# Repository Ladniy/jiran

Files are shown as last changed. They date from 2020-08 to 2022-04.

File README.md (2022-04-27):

# Jiran

This work is licensed under a
[Creative Commons Attribution-NonCommercial-ShareAlike 4.0 International License][cc-by-nc-sa].

[][cc-by-nc-sa]

[cc-by-nc-sa]: http://creativecommons.org/licenses/by-nc-sa/4.0/
[cc-by-nc-sa-image]: https://licensebuttons.net/l/by-nc-sa/4.0/88x31.png
[cc-by-nc-sa-shield]: https://img.shields.io/badge/License-CC%20BY--NC--SA%204.0-lightgrey.svg

Jiran is a 6x4 matrix ergo keyboard with additional 3 thumb and 1 pinky keys.



Based on the [Jian](https://github.com/KGOH/Jian-Info) keyboard.

* __Author:__ [t.me/ladniys](https://t.me/ladniys) [u/Ladniy](https://reddit.com/u/Ladniy)
* __Layout:__ [keyboard-layout-editor.com](http://www.keyboard-layout-editor.com/#/gists/0547cd126f61f8c3f76b0a9952901da4)
* __Hardware Availability:__ [Free to use](https://github.com/Ladniy/jiran/releases/tag/v1.0)
* __Firmware:__ [QMK](https://github.com/qmk/qmk_firmware)
* __Building guide:__ [Wiki](https://github.com/Ladniy/jiran/wiki)

Check out [wiki-page](https://github.com/Ladniy/jiran/wiki) for more information.

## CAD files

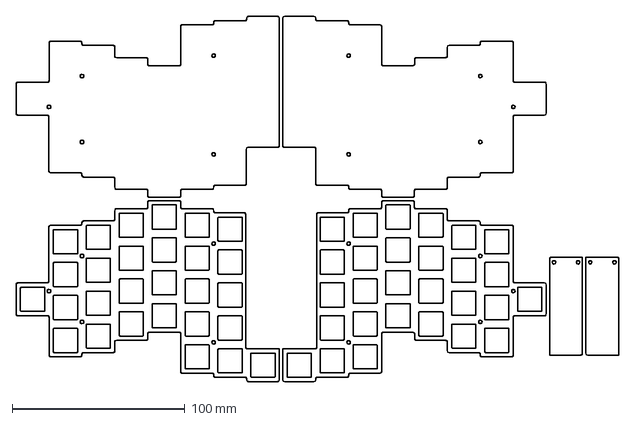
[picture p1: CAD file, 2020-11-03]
case/other-material/case.dxf
348.8 x 211.3 mm

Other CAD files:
case/other-material/case.dwg

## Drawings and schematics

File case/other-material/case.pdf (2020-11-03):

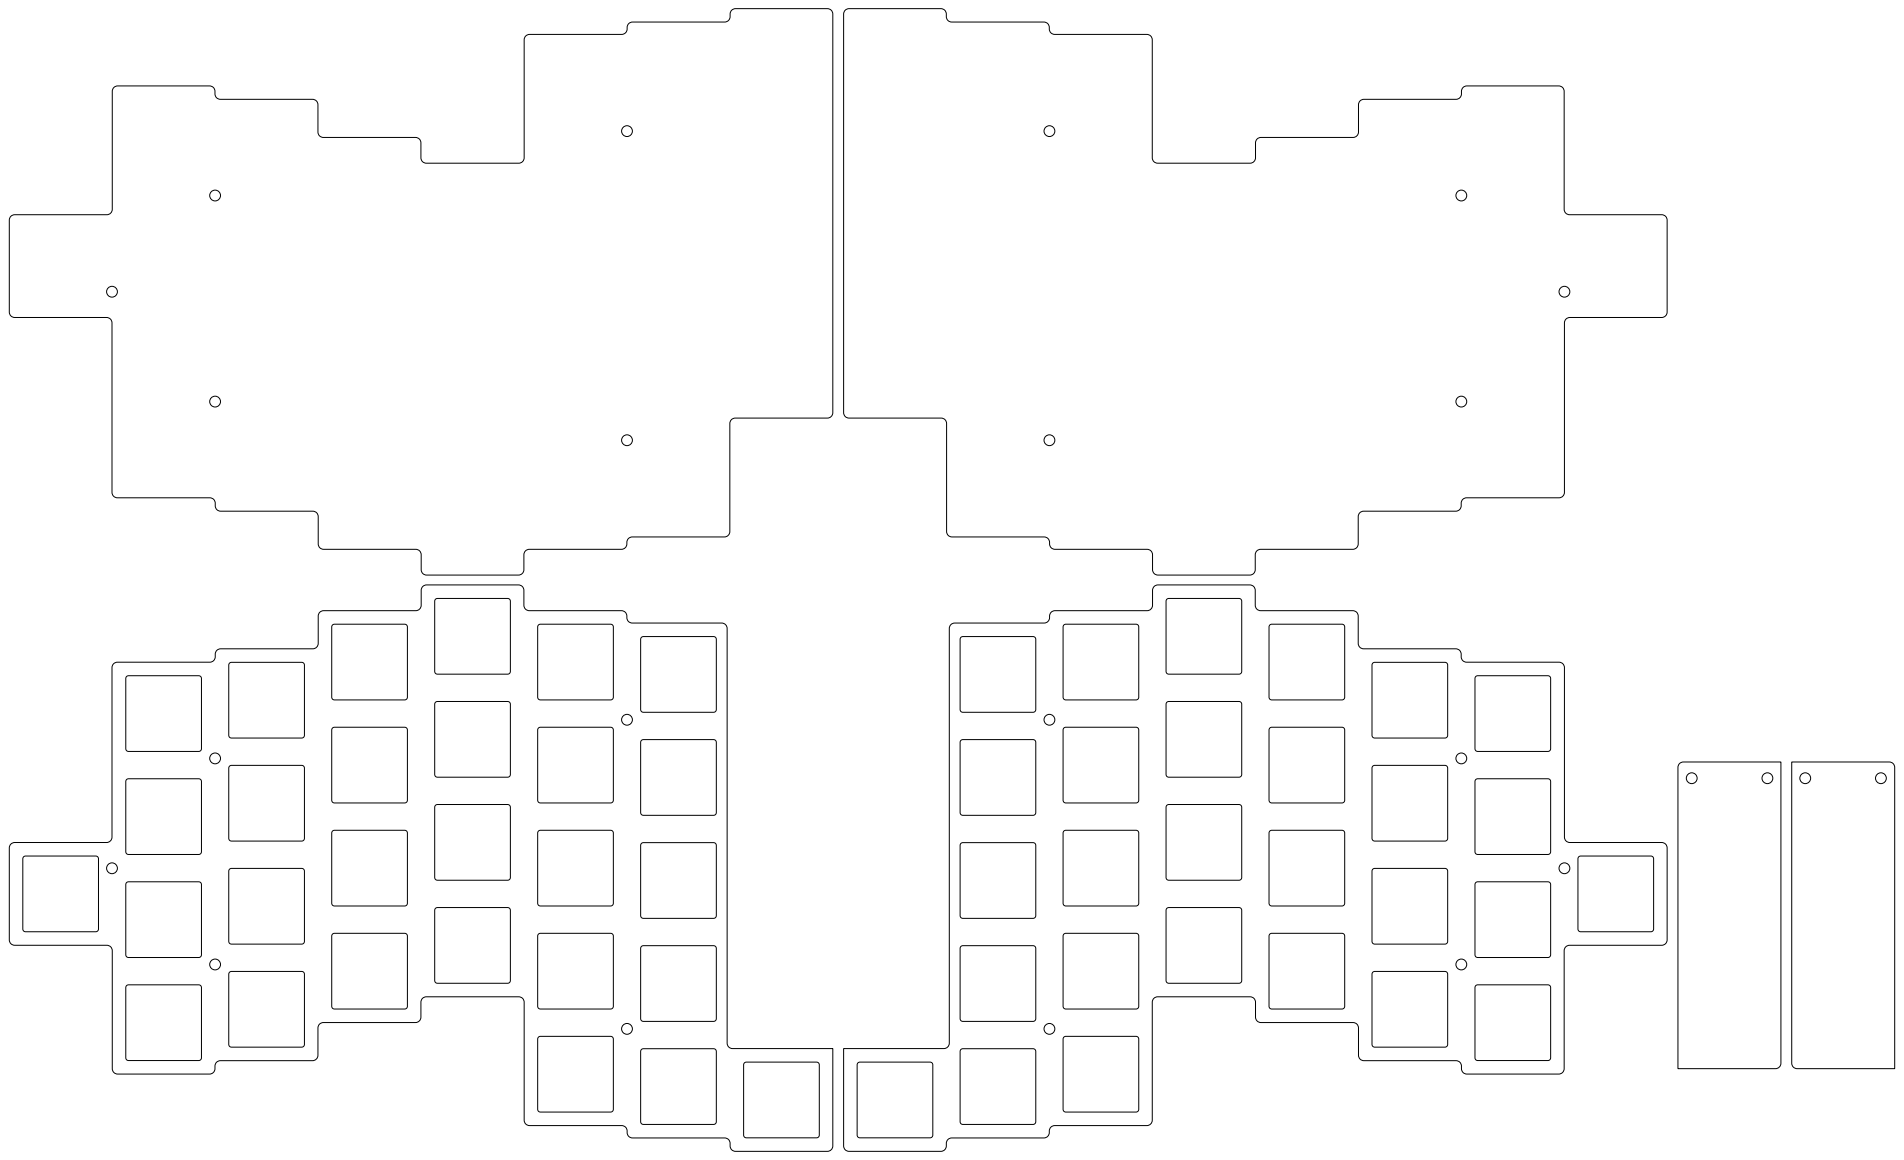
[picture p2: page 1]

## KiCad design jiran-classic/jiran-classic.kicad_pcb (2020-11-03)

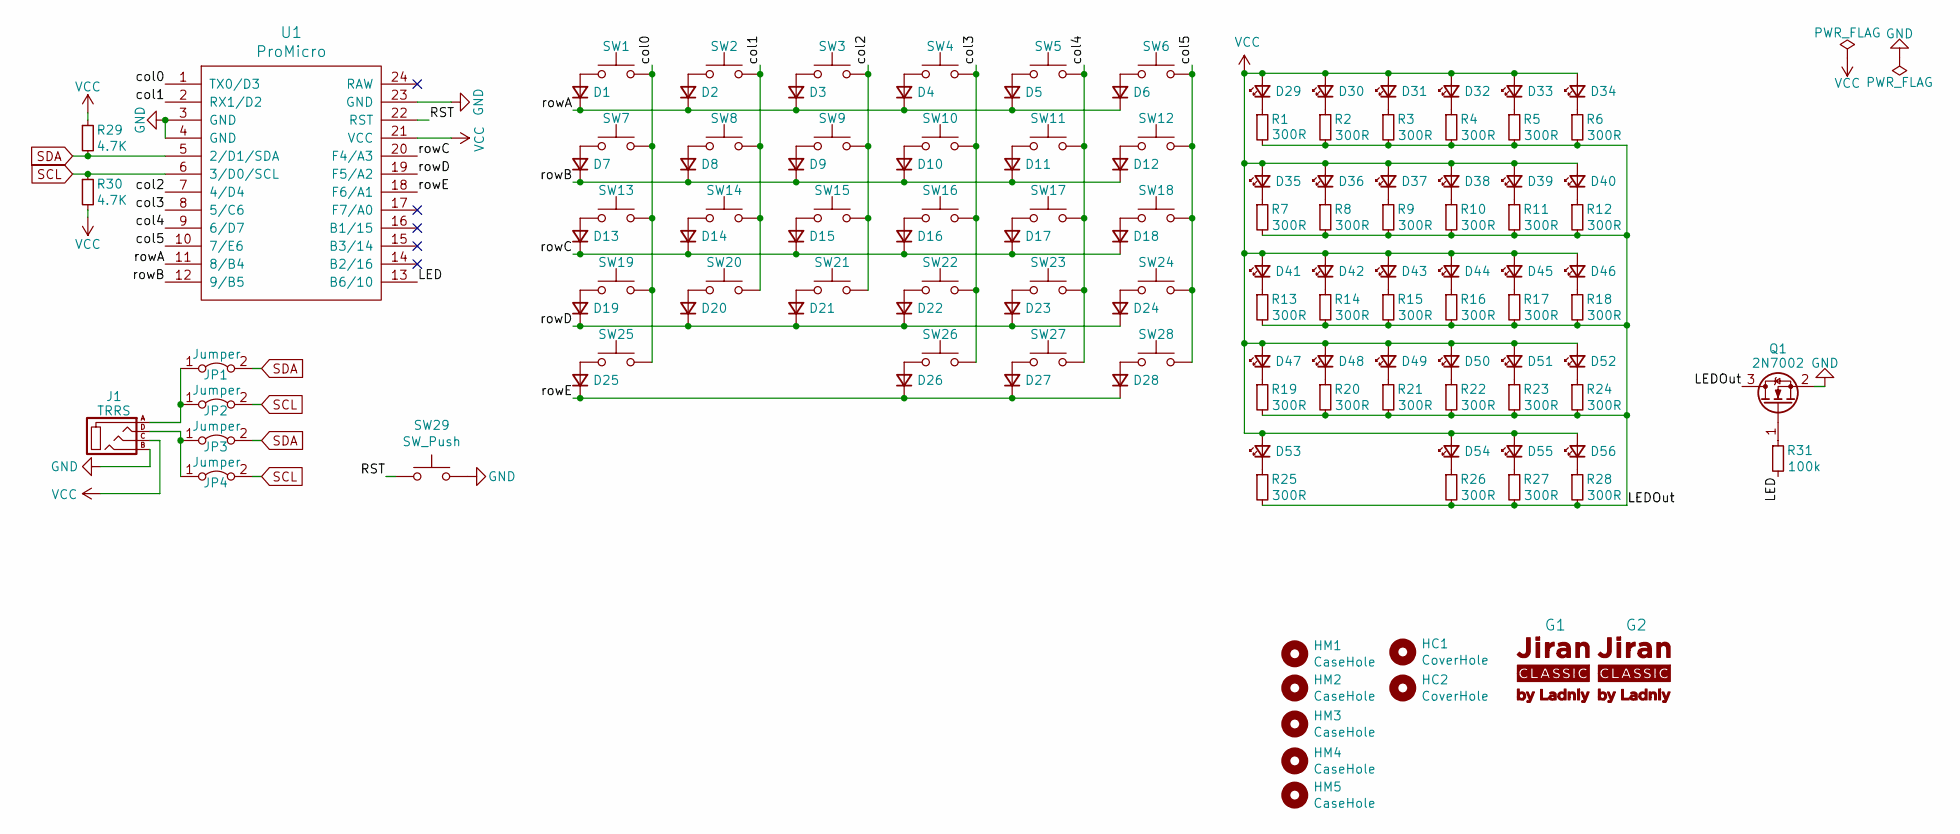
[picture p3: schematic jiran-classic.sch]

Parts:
D1, D2, D3, D4, D5, D6, D7, D8, D9, D10, D11, D12, D13, D14, D15, D16, D17, D18, D19, D20, D21, D22, D23, D24, D25, D26, D27, D28: 1N4148; Diode_Hybrid_SOD-123
D29, D30, D31, D32, D33, D34, D35, D36, D37, D38, D39, D40, D41, D42, D43, D44, D45, D46, D47, D48, D49, D50, D51, D52, D53, D54, D55, D56: LED_Small; LED_THT
G1, G2: logo-jiran-classic; Silk_Logo_Classic
HC1, HC2: CoverHole; Hole_Cover_M2
HM1, HM2, HM3, HM4, HM5: CaseHole; Hole_Mount_M4
J1: TRRS; TRSS_DUAL_THT
JP1, JP2, JP3, JP4: Jumper; Jumper_SMD
Q1: 2N7002; Mosfet_SMD_Dual_SOT-23
R1, R2, R3, R4, R5, R6, R7, R8, R9, R10, R11, R12, R13, R14, R15, R16, R17, R18, R19, R20, R21, R22, R23, R24, R25, R26, R27, R28: 300R; Resistor_Hybrid_1205
R29, R30: 4.7K; Resistor_Hybrid_1205
R31: 100k; Resistor_Hybrid_1205
SW1, SW2, SW3, SW4, SW5, SW6, SW7, SW8, SW9, SW10, SW11, SW12, SW13, SW14, SW15, SW16, SW17, SW18, SW19, SW20, SW21, SW22, SW23, SW24, SW25, SW26, SW27, SW28: SW_Push; Switch_MxAlpsChoc_MillMax_1u
SW29: SW_Push; Switch_Reset_THT
U1: ProMicro; ProMicro_Dual

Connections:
/LED: R31.2, U1.13 (B6/10)
/LEDOut: Q1.3 (D), R1.2, R2.2, R3.2, R4.2, R5.2, R6.2, R7.2, R8.2, R9.2, R10.2, R11.2, R12.2, R13.2, R14.2, R15.2, R16.2, R17.2, R18.2, R19.2, R20.2, R21.2, R22.2, R23.2, R24.2, R25.2, R26.2, R27.2, R28.2
/RST: SW29.1, U1.22 (RST)
/col0: SW1.2, SW7.2, SW13.2, SW19.2, SW25.2, U1.1 (TX0/D3)
/col1: SW2.2, SW8.2, SW14.2, SW20.2, U1.2 (RX1/D2)
/col2: SW3.2, SW9.2, SW15.2, SW21.2, U1.7 (4/D4)
/col3: SW4.2, SW10.2, SW16.2, SW22.2, SW26.2, U1.8 (5/C6)
/col4: SW5.2, SW11.2, SW17.2, SW23.2, SW27.2, U1.9 (6/D7)
/col5: SW6.2, SW12.2, SW18.2, SW24.2, SW28.2, U1.10 (7/E6)
/rowA: D1.1 (K), D2.1 (K), D3.1 (K), D4.1 (K), D5.1 (K), D6.1 (K), U1.11 (8/B4)
/rowB: D7.1 (K), D8.1 (K), D9.1 (K), D10.1 (K), D11.1 (K), D12.1 (K), U1.12 (9/B5)
/rowC: D13.1 (K), D14.1 (K), D15.1 (K), D16.1 (K), D17.1 (K), D18.1 (K), U1.20 (F4/A3)
/rowD: D19.1 (K), D20.1 (K), D21.1 (K), D22.1 (K), D23.1 (K), D24.1 (K), U1.19 (F5/A2)
/rowE: D25.1 (K), D26.1 (K), D27.1 (K), D28.1 (K), U1.18 (F6/A1)
GND: J1.B, Q1.2 (S), SW29.2, U1.3 (GND), U1.4 (GND), U1.23 (GND)
unnamed: D1.2 (A), SW1.1
unnamed: D2.2 (A), SW2.1
unnamed: D3.2 (A), SW3.1
unnamed: D4.2 (A), SW4.1
unnamed: D5.2 (A), SW5.1
unnamed: D6.2 (A), SW6.1
unnamed: D7.2 (A), SW7.1
unnamed: D8.2 (A), SW8.1
unnamed: D9.2 (A), SW9.1
unnamed: D10.2 (A), SW10.1
unnamed: D11.2 (A), SW11.1
unnamed: D12.2 (A), SW12.1
unnamed: D13.2 (A), SW13.1
unnamed: D14.2 (A), SW14.1
unnamed: D15.2 (A), SW15.1
unnamed: D16.2 (A), SW16.1
unnamed: D17.2 (A), SW17.1
unnamed: D18.2 (A), SW18.1
unnamed: D19.2 (A), SW19.1
unnamed: D20.2 (A), SW20.1
unnamed: D21.2 (A), SW21.1
unnamed: D22.2 (A), SW22.1
unnamed: D23.2 (A), SW23.1
unnamed: D24.2 (A), SW24.1
unnamed: D25.2 (A), SW25.1
unnamed: D26.2 (A), SW26.1
unnamed: D27.2 (A), SW27.1
unnamed: D28.2 (A), SW28.1
unnamed: D29.1 (K), R1.1
unnamed: D30.1 (K), R2.1
unnamed: D31.1 (K), R3.1
unnamed: D32.1 (K), R4.1
unnamed: D33.1 (K), R5.1
unnamed: D34.1 (K), R6.1
unnamed: D35.1 (K), R7.1
unnamed: D36.1 (K), R8.1
unnamed: D37.1 (K), R9.1
unnamed: D38.1 (K), R10.1
unnamed: D39.1 (K), R11.1
unnamed: D40.1 (K), R12.1
unnamed: D41.1 (K), R13.1
unnamed: D42.1 (K), R14.1
unnamed: D43.1 (K), R15.1
unnamed: D44.1 (K), R16.1
unnamed: D45.1 (K), R17.1
unnamed: D46.1 (K), R18.1
unnamed: D47.1 (K), R19.1
unnamed: D48.1 (K), R20.1
unnamed: D49.1 (K), R21.1
unnamed: D50.1 (K), R22.1
unnamed: D51.1 (K), R23.1
unnamed: D52.1 (K), R24.1
unnamed: D53.1 (K), R25.1
unnamed: D54.1 (K), R26.1
unnamed: D55.1 (K), R27.1
unnamed: D56.1 (K), R28.1
unnamed: J1.A, JP1.1 (A), JP2.1 (A)
unnamed: J1.D, JP3.1 (A), JP4.1 (A)
unnamed: Q1.1 (G), R31.1
SCL: JP2.2 (B), JP4.2 (B), R30.1, U1.6 (3/D0/SCL)
SDA: JP1.2 (B), JP3.2 (B), R29.2, U1.5 (2/D1/SDA)
VCC: D29.2 (A), D30.2 (A), D31.2 (A), D32.2 (A), D33.2 (A), D34.2 (A), D35.2 (A), D36.2 (A), D37.2 (A), D38.2 (A), D39.2 (A), D40.2 (A), D41.2 (A), D42.2 (A), D43.2 (A), D44.2 (A), D45.2 (A), D46.2 (A), D47.2 (A), D48.2 (A), D49.2 (A), D50.2 (A), D51.2 (A), D52.2 (A), D53.2 (A), D54.2 (A), D55.2 (A), D56.2 (A), J1.C, R29.1, R30.2, U1.21 (VCC)

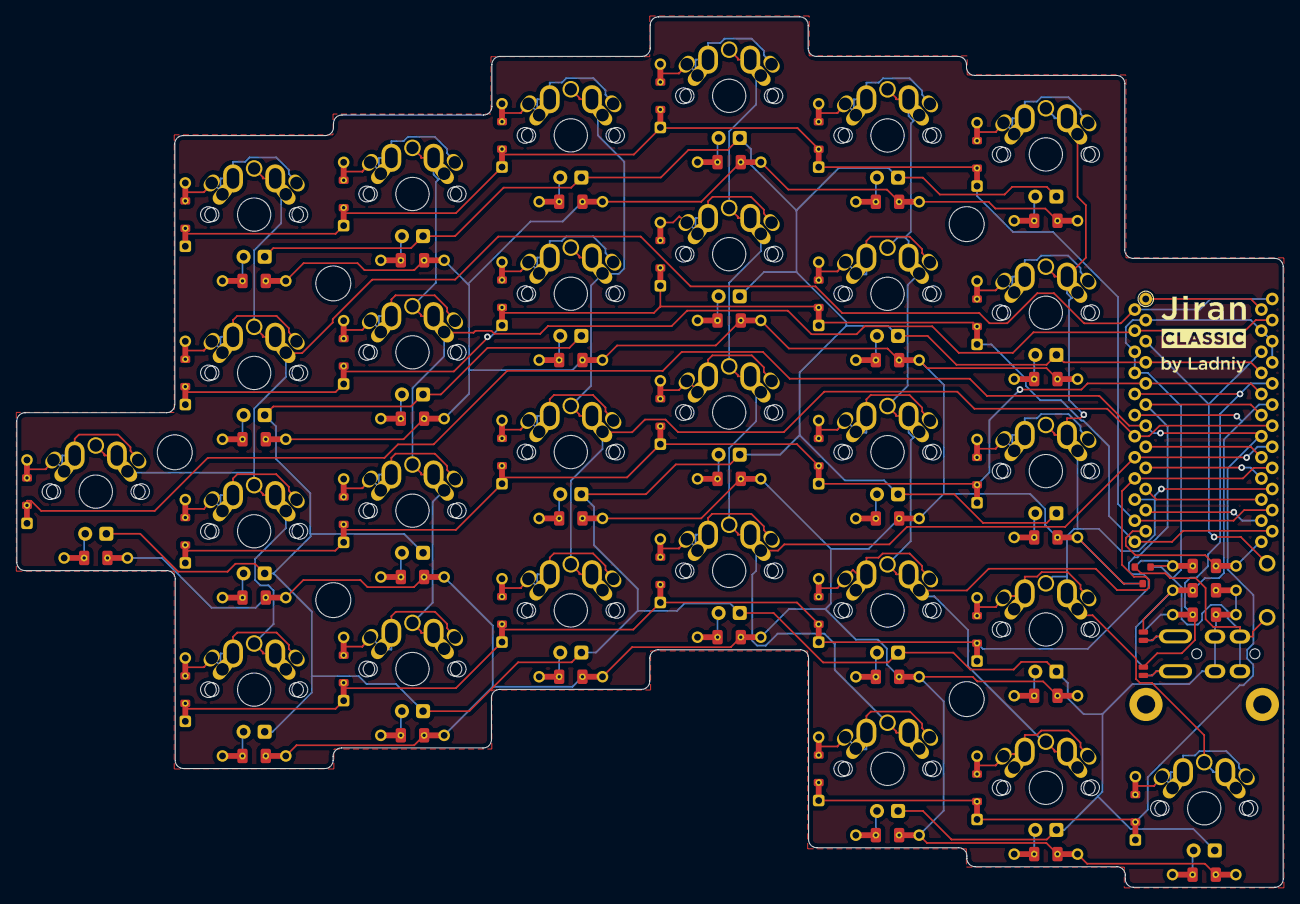
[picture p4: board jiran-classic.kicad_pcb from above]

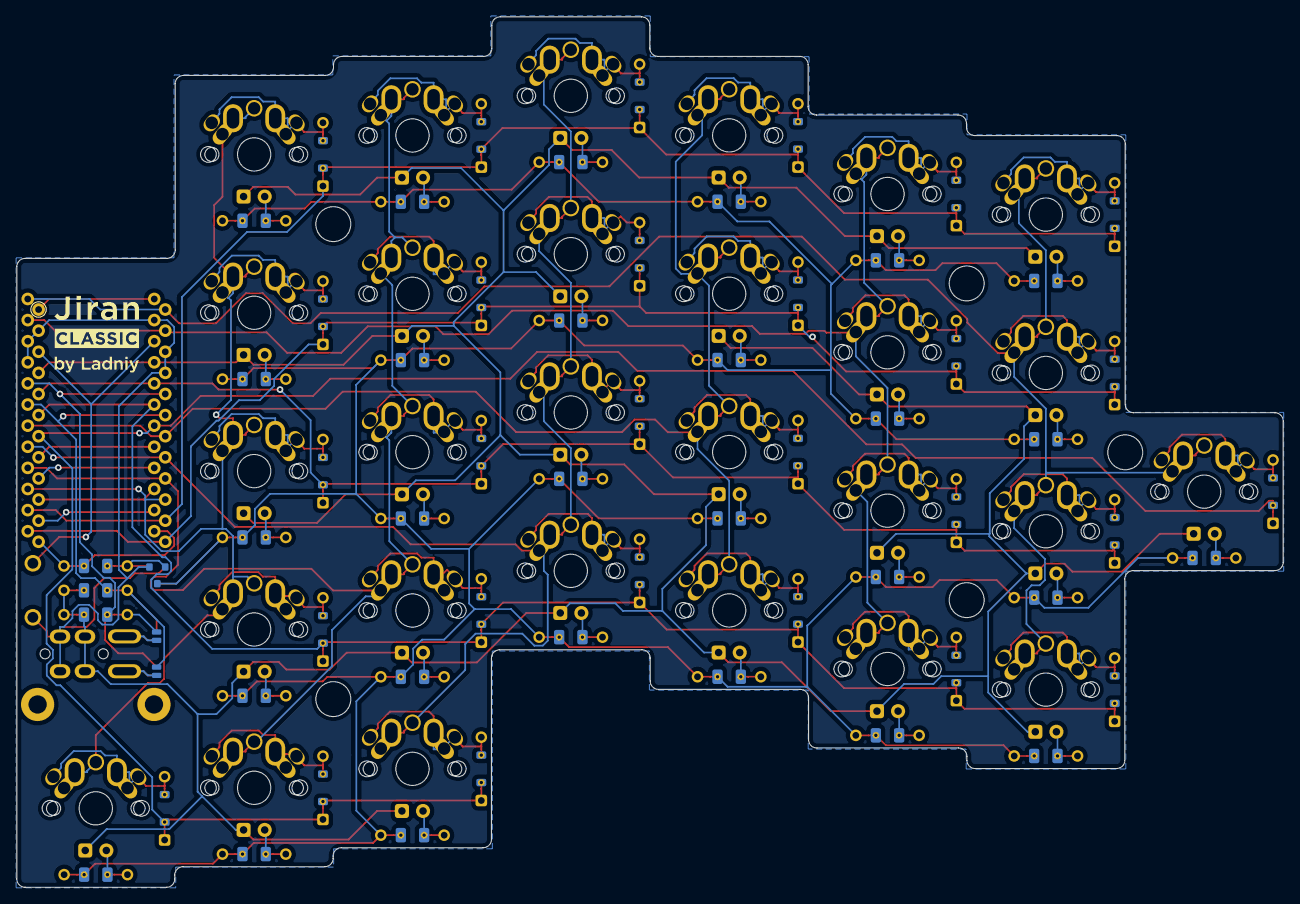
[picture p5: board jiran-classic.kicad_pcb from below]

Board: 2 copper layers, 152.3 x 104.7 mm, 132 parts (3 on the bottom side), 77 nets.

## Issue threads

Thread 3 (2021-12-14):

Plate issue (jlcpcb)

Kejchi, 2021-12-14:
Maybe you should change the plate gerber file?
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

Ladniy, 2021-12-14:
No. You must write to them "cut them as non-plated slot". This follows from their message.
This is problem with JLCPCB only, other fabric have no problems with this footprint.

Closed 2021-12-14.

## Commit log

2020-02-12 Add old files
    [Pcb-B_Cu.gbl, Pcb-B_Mask.gbs, Pcb-B_SilkS.gbo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]
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2020-02-12 Update footprint
    [Pcb.sch]
2020-02-12 Remove reference from PCB
    [Pcb.kicad_pcb]
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2020-02-13 Add one more mount hole
    [Pcb.kicad_pcb]
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2020-02-13 Remove case silkscreen
    [Pcb.kicad_pcb]
2020-02-13 Remove outline zone
    [Pcb.kicad_pcb]
2020-02-14 Create cutout for pinky key
    [Pcb.kicad_pcb]
2020-02-14 Update dsn file for route
    [Pcb.dsn]
2020-02-14 Route and fill all zones
    [Pcb.kicad_pcb]
2020-02-16 Unfill all zones
    [Pcb.kicad_pcb]
2020-02-20 Remove lock leds
    [Pcb.sch]
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2020-02-20 Add JST pin for battery
    [Pcb.sch]
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2020-02-22 Remove I2C resistors
    [Pcb.kicad_pcb, Pcb.sch]
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2020-02-24 Remove JST connector from scheme
    [Pcb.sch]
2020-02-25 Add label for SCL
    [Pcb.sch]
2020-02-25 Add 4.7k resistor for I2C
    [Pcb.sch]
2020-02-25 Add jumpers for TRRS jack
    [Pcb.sch]
2020-02-25 Add value for resistors
    [Pcb.sch]
2020-02-25 Add value for diodes
    [Pcb.sch]
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2020-02-26 Add footprints for resistors and jumpers
    [Pcb.sch]
2020-02-26 Placed resistors and jumpers
    [Pcb.kicad_pcb]
2020-02-26 Add logo
    [Pcb.kicad_pcb]
2020-02-26 Route tracks
    [Pcb.dsn, Pcb.kicad_pcb]
2020-02-26 Fill all zones
    [Pcb.kicad_pcb]
2020-02-26 Update silkscreen at PCB
    [Pcb.kicad_pcb]
2020-02-26 Remove old gerbers file
    [Pcb-B_Cu.gbl, Pcb-B_Mask.gbs, Pcb-B_SilkS.gbo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]
2020-02-26 Create gerber file for new silkscreen
    [Pcb-B_Cu.gbl, Pcb-B_Mask.gbs, Pcb-B_SilkS.gbo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]
2020-02-26 Remove gerbers file with new silkscreen
    [Pcb-B_Cu.gbl, Pcb-B_Mask.gbs, Pcb-B_SilkS.gbo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]
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2020-02-26 Summ update
    [Pcb.kicad_pcb]
2020-02-26 Small fix
    [Pcb.kicad_pcb]
2020-02-26 Create PCB and gerber files for FR-4 plate
    [plate.kicad_pcb]
2020-02-26 Create PCB and gerber files for FR-4 underplate
    [underplate.kicad_pcb]
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2020-02-28 Create PCB and gerber for cover
    [cover.kicad_pcb, cover.sch]
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2020-03-06 Create files for FR-4 cover
    [cover.kicad_pcb]
2020-03-06 Create gerber files for FR-4 cover
    [cover-B_Cu.gbl, cover-B_Mask.gbs, cover-Edge_Cuts.gm1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]
2020-03-06 Create zip archive with gerber files
    [cover-B_SilkS.gbo]
2020-03-06 Create gerber files for FR-4 plate
    [plate-B_Cu.gbl, plate-B_Mask.gbs, plate-B_SilkS.gbo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]
2020-03-06 Some fix
    [plate.kicad_pcb]
2020-03-08 Remove unused files
    [cover.sch]
2020-03-08 Add silk at PCB
    [cover.kicad_pcb]
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2020-03-08 Create gerbers files for cover
    [cover-B_Cu.gbl, cover-B_Mask.gbs, cover-B_SilkS.gbo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]
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2020-03-08 Create gerbers files for plate
    [plate-B_Cu.gbl, plate-B_Mask.gbs, plate-B_SilkS.gbo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]
2020-03-08 Add new footprint for cutouts
    [plate.kicad_pcb]
2020-03-08 Update hole positions
    [underplate.kicad_pcb]
2020-03-08 Create gerber files for underplate PCB
    [underplate-B_Cu.gbl, underplate-B_Mask.gbs, underplate-B_SilkS.gbo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]
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2020-03-12 Fix PCB and gerber files for FR-4 cover
    [cover-B_Cu.gbl, cover-B_Mask.gbs, cover-B_SilkS.gbo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]
2020-03-12 Create and modify catalog with no pinky case files
    [Case.dwg, Case.dxf]
2020-03-12 Create and modify catalog with pinky case files
    [Case.dwg, Case.dxf]
2020-03-12 Remove old files
    [Plate.dwg, Plate.dxf]
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2020-04-02 create other catalog for both version
    [Pcb.dsn, Pcb.kicad_pcb, Pcb.sch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]
2020-04-02 move footrints catalog
    [Pcb.dsn, Pcb.kicad_pcb, Pcb.sch]
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2020-04-02 add new logo silkscreen
    [pcb.kicad_pcb]
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2020-04-07 Remove old gerber files for plate
    [plate-B_Cu.gbl, plate-B_Mask.gbs, plate-B_SilkS.gbo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]
2020-04-07 Update footprints
    [plate.kicad_pcb]
2020-04-07 Plot gerber files
    [plate-B_Cu.gbl, plate-B_Mask.gbs, plate-B_SilkS.gbo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]
2020-04-13 Route file
    [pcb.dsn]
2020-04-13 Increase jumper size
    [plate.kicad_pcb]
2020-04-13 Remove old gerber files
    [plate-B_Cu.gbl, plate-B_Mask.gbs, plate-B_SilkS.gbo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]
2020-04-13 Plot new gerber files
    [plate-B_Cu.gbl, plate-B_Mask.gbs, plate-B_SilkS.gbo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]
2020-05-30 Decrease distance between switch hole and right side
    [plate.kicad_pcb]
2020-05-31 Remove RGB leds
    [pcb.sch]
2020-05-31 Uhfill all zones
    [pcb.kicad_pcb]
2020-05-31 Remove tracks from PCb
    [pcb.kicad_pcb]
2020-05-31 Remove RGB leds footprints
    [pcb.kicad_pcb]
2020-05-31 Add logos
    [pcb.kicad_pcb]
2020-05-31 Export new DSN file
    [pcb.dsn]
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2020-08-01 Rename of all files
    [case.dwg, case.dxf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]
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2020-09-17 Replace some footprint
    [Pcb.sch]
2020-09-18 Regenerate new dsn file
    [Pcb.dsn]
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2020-09-18 Remove case files for 44 keys version
    [case.dwg, case.dxf]
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2020-09-18 Add holes for mount
    [plate.kicad_pcb]
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2020-11-02 Add logo as symbol
    [Pcb.sch]
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2020-11-02 Assign logo symbols with logo footprints
    [Pcb.sch]
2020-11-02 Remove one hole mount (HM3)
    [Pcb.kicad_pcb, Pcb.sch]
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2020-11-02 Update dsn and ses file for freerouting
    [Pcb.dsn]
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2020-11-02 Rename and delete some pcb files
    [jiran-hotswap.kicad_pcb, jiran-hotswap.sch, pcb.dsn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]
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2020-11-02 Update logo, change switch footprints, move diode footprints
    [jiran-hotswap.kicad_pcb]
2020-11-02 Fix gerber
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2020-11-03 Update logos on pcb
    [jiran-cherry.kicad_pcb]
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2020-11-03 Move files in other folder
    [case.dwg, case.dxf]
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2020-11-03 Update other files format
    [case.dxf]
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

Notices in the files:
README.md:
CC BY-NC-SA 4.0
